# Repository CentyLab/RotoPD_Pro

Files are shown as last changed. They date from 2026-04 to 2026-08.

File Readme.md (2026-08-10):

## RotoPD Pro - USB-C PD 3.1 Breakout I2C 240W
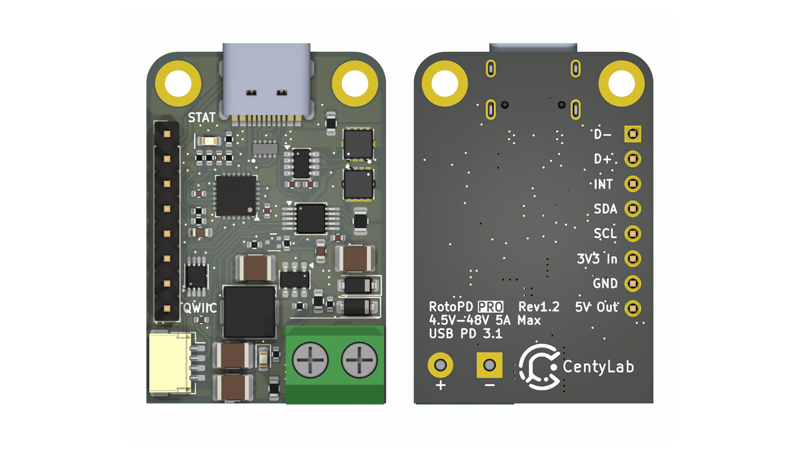
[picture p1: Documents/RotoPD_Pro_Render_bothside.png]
Render


## Related Links
- [AP33772S Arduino - GitHub](https://github.com/CentyLab/AP33772S-CentyLab)
- [INA238 Arduino - GitHub](https://github.com/RobTillaart/INA238)
- [RotoPD Pro Project - Hackaday](https://hackaday.io/project/204943-rotopd-pro-usb-c-240w-breakout-i2c)

You can install the libraries directly on ArduinoIDE. Library version 1.1.0 and later will support RotoPD Pro

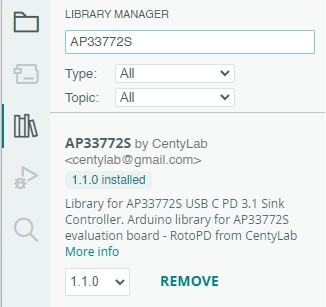
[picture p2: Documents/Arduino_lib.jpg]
AP33772SLib


## Description

While traditional power adapters can provide a variety of current but fixed to 5V output, our RotoPD Pro leverages advanced power delivery protocols to achieve a versatile output range — 4.5V to 48V at 240W max. The breakout board use a stand alone Power Delivery Sink controller to negotiate with your modern charger and provide different output voltage.

Centylab's RotoPD Pro can unlock more advance mode in your USB-C power supplies like Programmable Power Supply (PPS) and Adjustable Voltage Supply (AVS), to provide even more granular voltage adjustment. The RotoPD Pro simplifies power negotiation with USB-C adapters, handling the complex process of establishing power delivery contracts. The controller does all the heavy lifting of power negotiation and provides an easy way to configure over I2C, free your micro-controller from the complicated USB-C PD protocol.

To config the board, you will need an I2C bus. The board integrates seamlessly into the Qwiic and STEMMA QT ecosystems, no soldering is required. Unlike the previous version, the board only work with **3.3V I2C logic voltage.**

To make it even easier to use, RotoPD Pro includes a built-in buck converter that efficiently steps down USB-C VBUS power to a stable 5V output, making it perfect for powering microcontrollers, sensors, and other low-voltage components in your project.

## Requirements for AVS
To ultilize AVS power profile, you will need a powerbank or charger that has AVS profile and a 240W USB-C cable. Here are some chargers that we found support AVS profile.

+ [Framework 180W](https://frame.work/products/16-power-adapter)

+ [Framework 240W](https://frame.work/products/power-adapter-240w)

+ [AMEGAT Powerbank 140W](https://www.amazon.com/AMEGAT-27600mAh-Portable-Recharge-Compatible/dp/B0CC2CGD3L)

+ [Baseus Powerbank 140W](https://www.amazon.com/Baseus-Portable-Charger-24000mAh-Charging/dp/B0CH8D2YHZ)

+ [UGREEEN Nexode 300W](https://www.amazon.com/UGREEN-Charger-Charging-Station-Compatible/dp/B0DBZY57ZF)

## Specification
+ Input and output voltage range of  48V at 5A max
+ On board buck for 5V output at 1A max, 0.4A continuous
+ Support Qwiic or STEMMA QT connector with 3.3V logic
+ Support PD3.1 EPR/AVS Up to 48V and SPR/PPS Up to 21V
+ Certified USB PD3.1 v1.6  TID: 10062
+ Integrated ESD and flyback diode protection
+ Integrated NTC temperature monitoring
+ On board VBUS switch (back-to-back NMOS)
+ Current sensing from 0 to 5 A at ±2% accuracy up to 60C

## Pinout
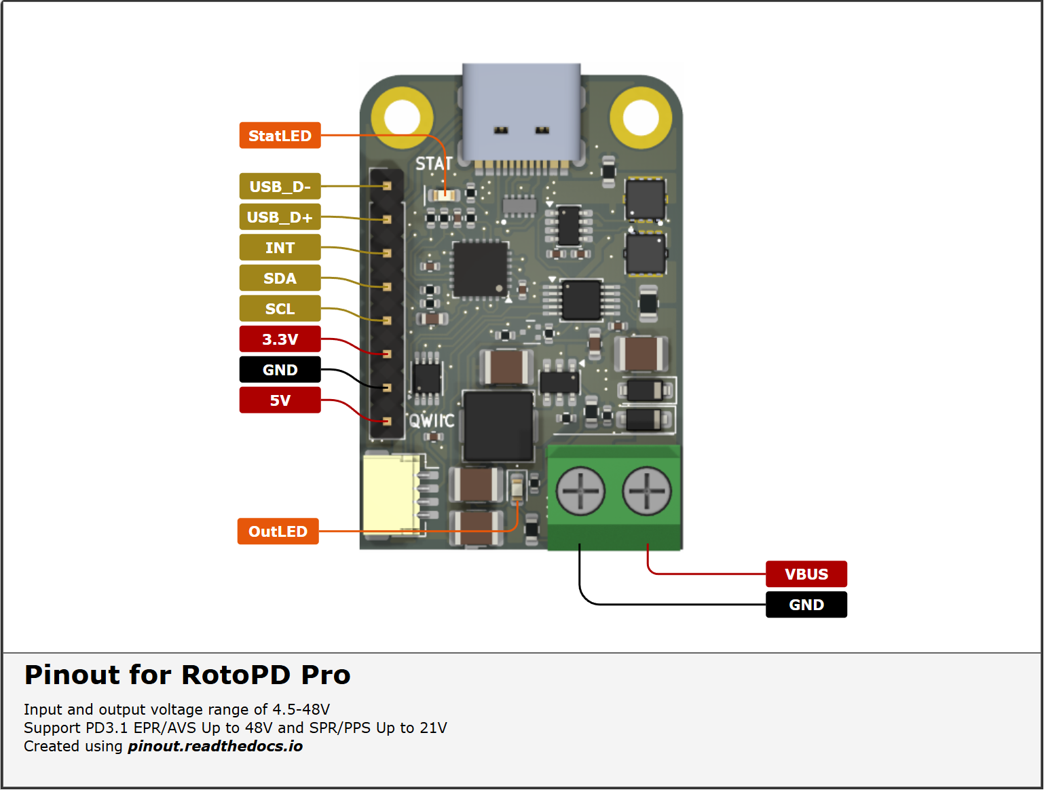
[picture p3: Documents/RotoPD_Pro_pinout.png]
Pinout

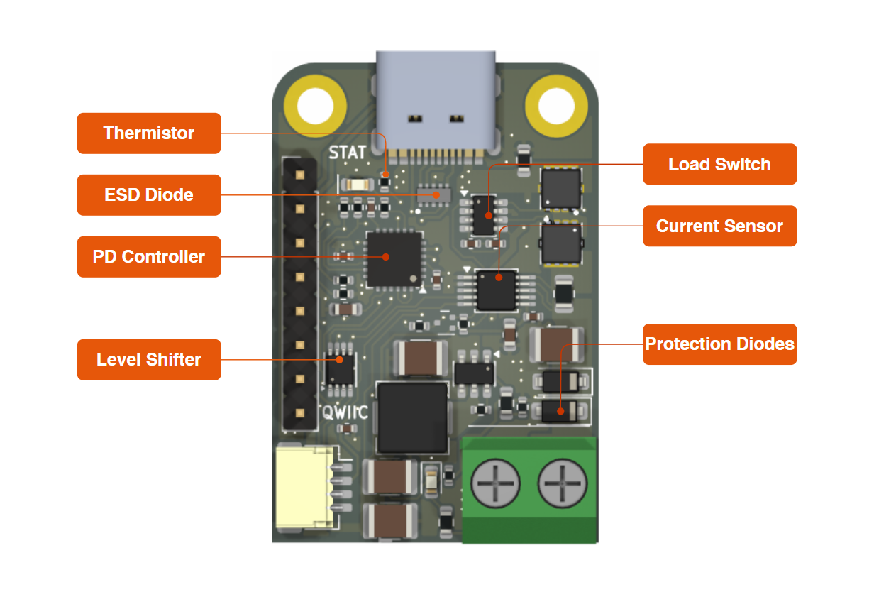
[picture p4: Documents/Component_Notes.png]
Components


## Schematic
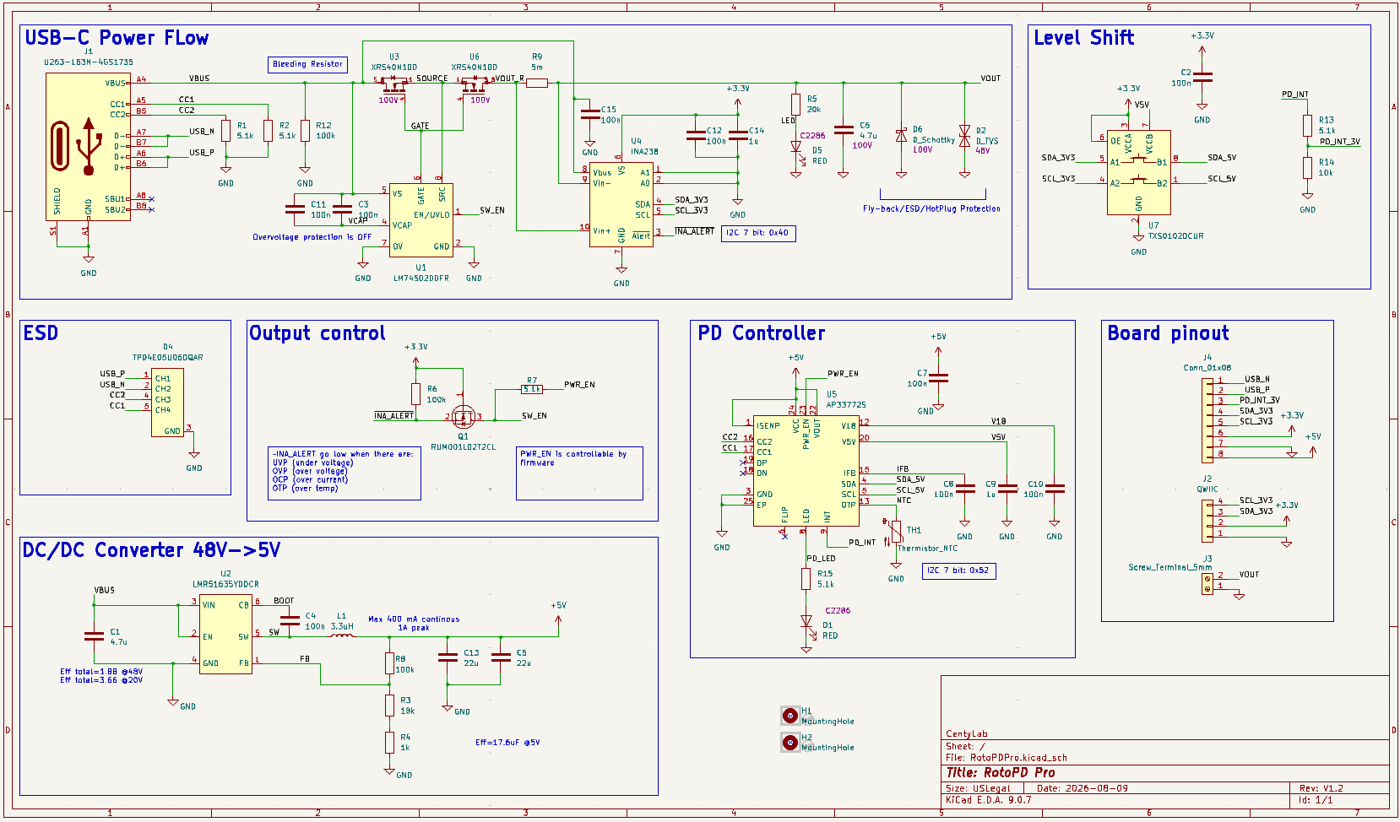
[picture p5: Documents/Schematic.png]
Schematic


## Demo
AVSCycle example with Sparkfun Pro Micro ESP32-C3. We are requesting AVS profile from 15V to 48V.

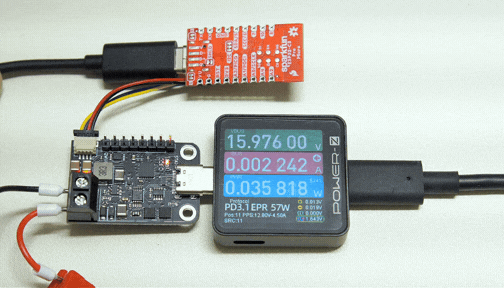
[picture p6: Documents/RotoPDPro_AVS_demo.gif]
ESP32C3_AVS_Step


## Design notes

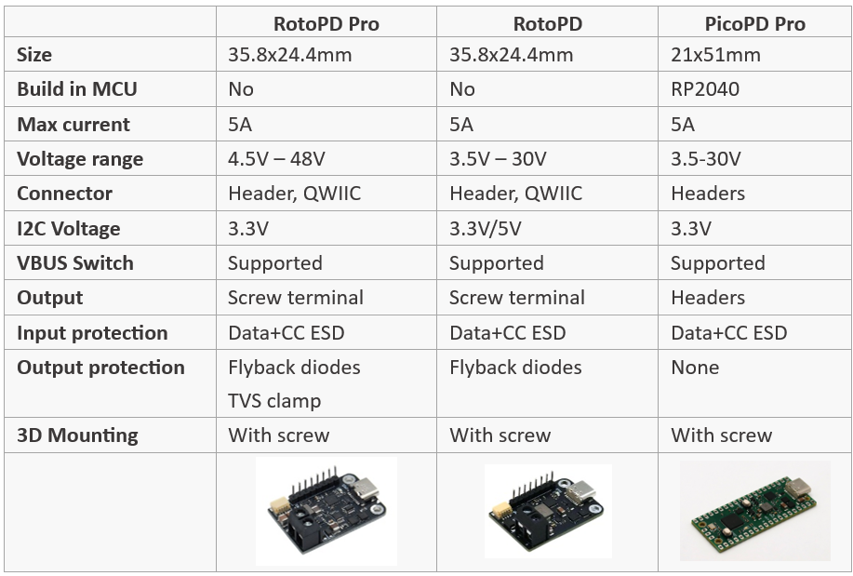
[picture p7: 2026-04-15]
Documents/Comparision_Table.png

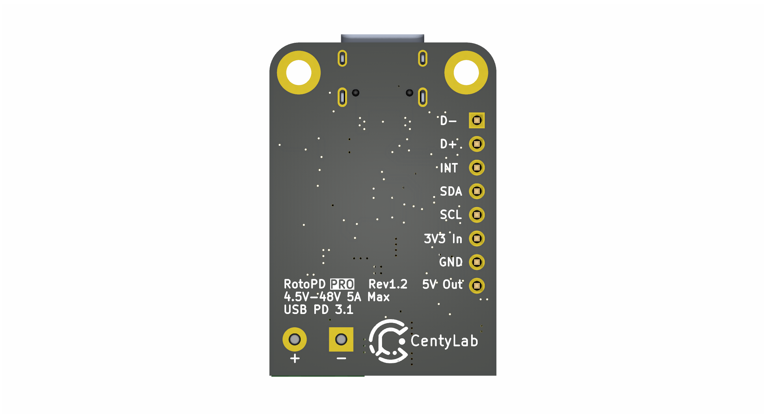
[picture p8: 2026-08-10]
Documents/Bottom_Render.png

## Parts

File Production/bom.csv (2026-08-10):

Designator | Footprint | Quantity | Value | LCSC Part #
C1, C6 | 1210 | 2 | 4.7u | C697607
C10, C11, C12, C15, C2, C3, C4, C7, C8 | 402 | 9 | 100n | C162179
C13, C5 | 1210 | 2 | 22u | C52306
C14, C9 | 603 | 2 | 1u | C15849
D1, D5 | 603 | 2 | RED | C2286
D2 | D_SOD-123F | 1 | D_TVS | C2994213
D4 | SON50P100X255X50-10N | 1 | TPD4E05U06DQAR | C138714
D6 | D_SOD-123 | 1 | D_Schottky | C908227
J1 | USB_C_XKB_240W | 1 | U263-163N-4GS1735 | C2931470
J2 | JST_SH_SM04B-SRSS-TB_1x04-1MP_P1.00mm_Horizontal | 1 | QWIIC | C160404
J3 | TerminalBlock_Phoenix_MKDS-1,5-2_1x02_P5.00mm_Horizontal | 1 | Screw_Terminal_5mm
J4 | PinHeader_1x08_P2.54mm_Vertical | 1 | Conn_01x08
L1 | L_APV_APH0530 | 1 | 3.3uH | C5349682
Q1 | SOT-723 | 1 | RUM001L02T2CL | C253528
R1, R13, R15, R2, R7 | 402 | 5 | 5.1k | C25905
R12 | 603 | 1 | 100k | C25803
R14 | 402 | 1 | 10k | C25744
R3 | 603 | 1 | 18k | C25810
R4 | 402 | 1 | 1k | C11702
R5 | 603 | 1 | 10k | C4184
R6, R8 | 402 | 2 | 100k | C25741
R9 | 805 | 1 | 5m | C22450690
TH1 | 402 | 1 | Thermistor_NTC | C77131
U1 | TSOT-23-8 | 1 | LM74502DDFR | C5219202
U2 | TSOT-23-6 | 1 | LMR51635YDDCR | C45262770
U3, U6 | DFN-8(3.3x3.3) | 2 | XRS40N10D | C50314150
U4 | VSSOP-10_3x3mm_P0.5mm | 1 | INA238 | C2868250
U5 | QFN-24-1EP_4x4mm_P0.5mm_EP2.6x2.6mm | 1 | AP33772S | C24374260
U7 | VSSOP-8_2.3x2mm_P0.5mm | 1 | TXS0102DCUR | C53434

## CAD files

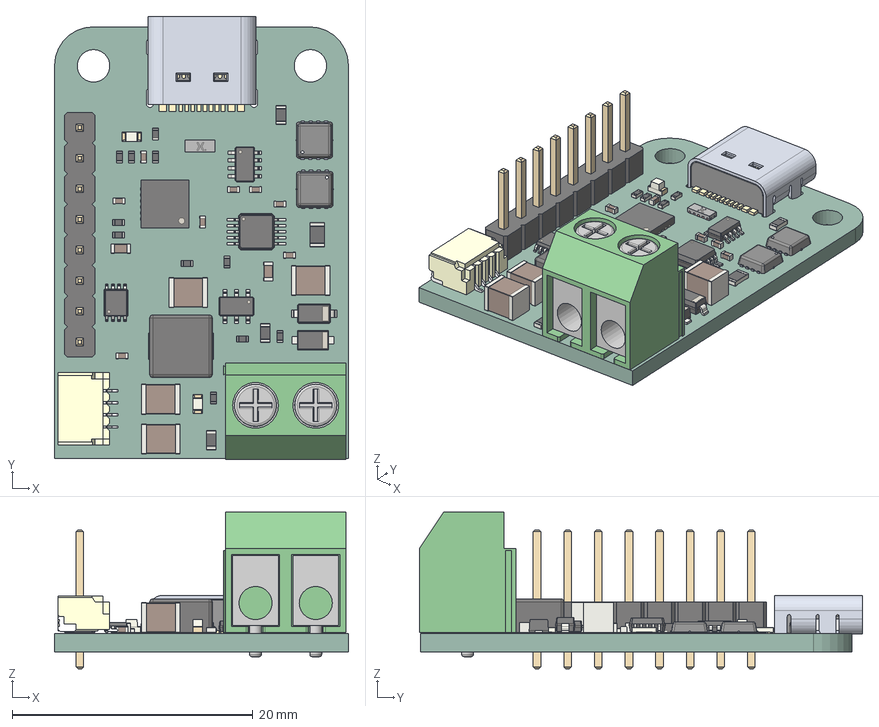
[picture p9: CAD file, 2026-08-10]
Documents/RotoPD_Pro.step
24.4 x 36.8 x 13.0 mm
LED_0603_1608Metric x 2
C_1210_3225Metric x 4
DFN-8(3.3x3.3) x 2
Screw Terminal Block 5mm 2-way
D_SOD-123
R_0603_1608Metric x 3
R_0402_1005Metric x 11
C_0402_1005Metric x 8
VSSOP-10_3x3mm_P0.5mm
TSOT-23-8
SOT1176 LF
SOT1176 Mold body
D_SOD-123F
C_0603_1608Metric x 2
L_APV_APH0530
SM04B-SRSS-TB(LF)(SN)
PinHeader_1x08_P2.54mm_Vertical
QFN-24-1EP_4x4mm_P0.5mm_EP2.6x2.6mm
VSSOP-8_2.3x2mm_P0.5mm
USBC_16P
R_0805_2012Metric
TSOT-23-6
RotoPDPro_PCB

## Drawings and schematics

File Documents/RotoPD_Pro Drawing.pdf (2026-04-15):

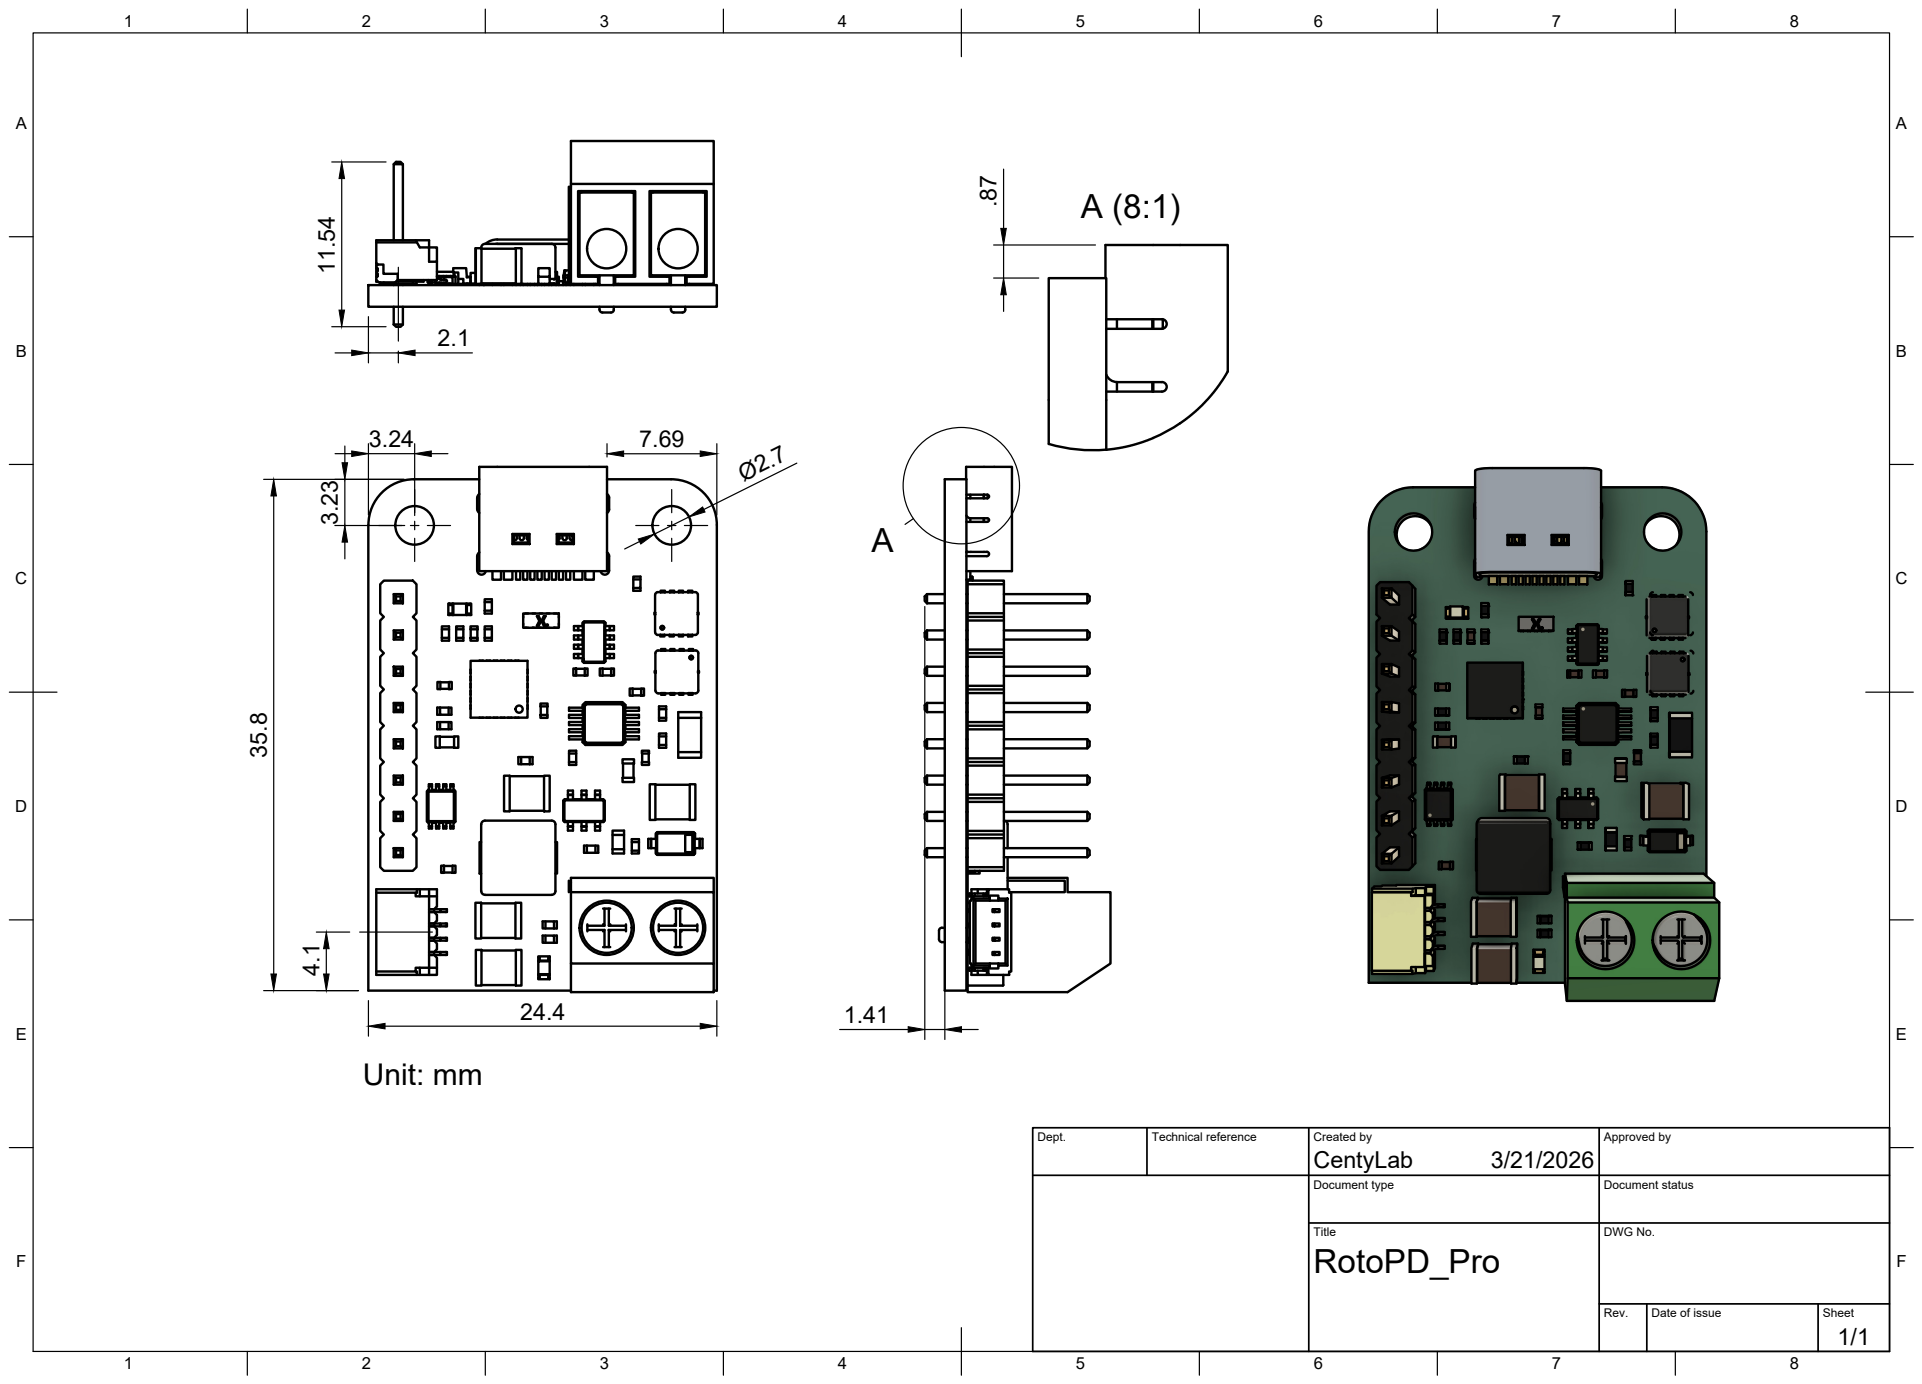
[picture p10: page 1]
Title; DWG No.; Rev.; Date of issue; Sheet; CentyLab 35.8; Unit: mm 3.23

Dept. | Technical reference | Created by 3/21/2026 | Approved by

Document type | Document status

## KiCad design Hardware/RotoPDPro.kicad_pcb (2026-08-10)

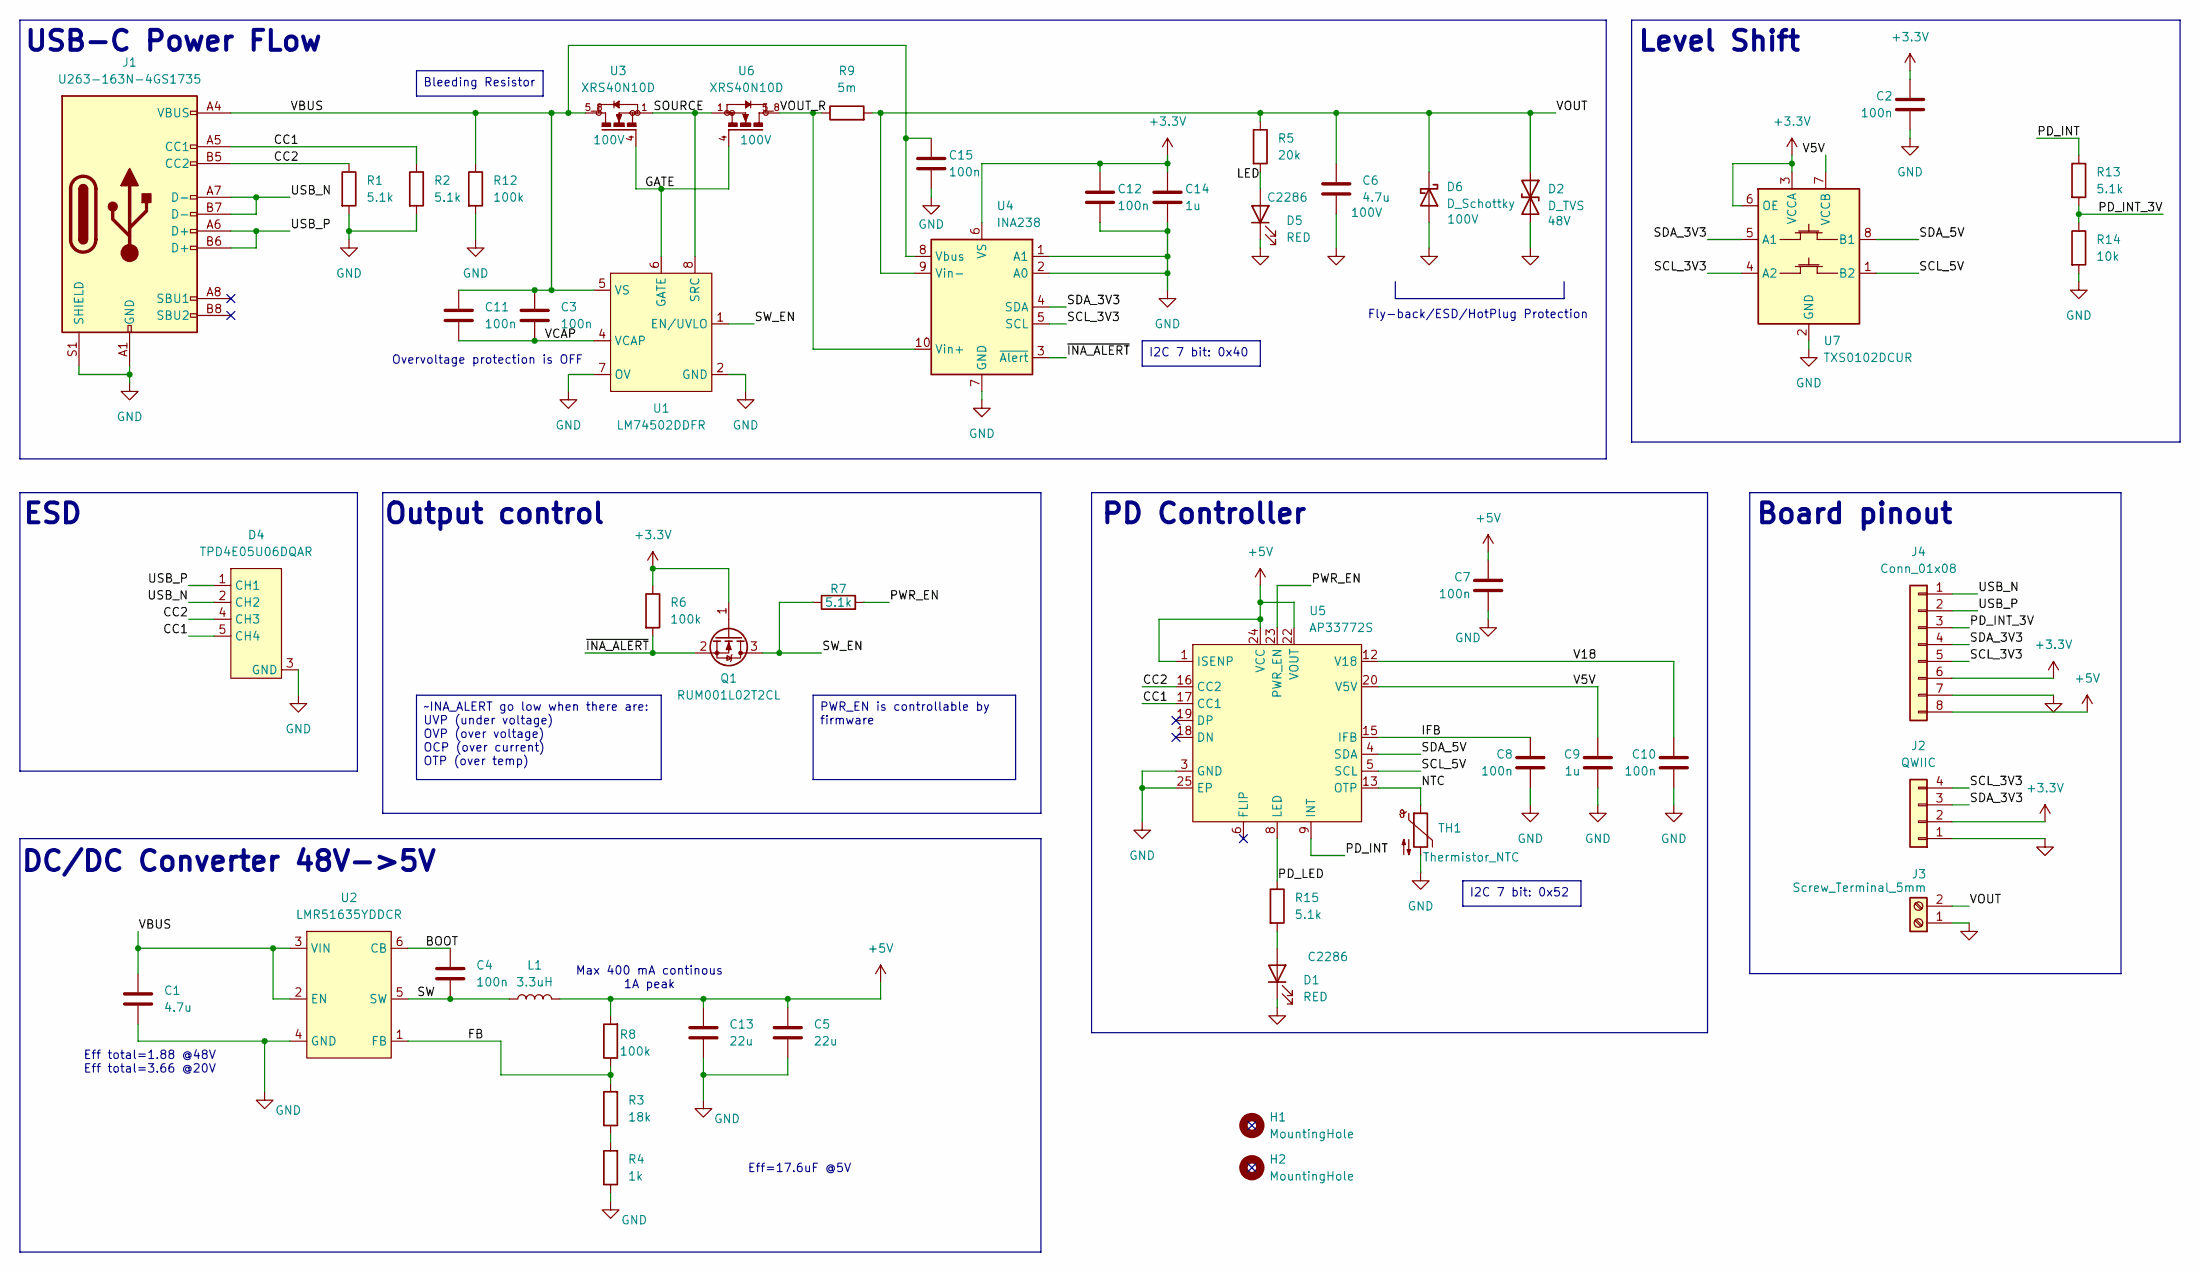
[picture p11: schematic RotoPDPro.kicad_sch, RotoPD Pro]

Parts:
C1: 4.7u; C_1210_3225Metric; LCSC C697607
C2, C3, C7, C8, C10, C11, C12, C15: 100n; C_0402_1005Metric; LCSC C162179
C4: 100n; R_0402_1005Metric; LCSC C162179
C5, C13: 22u; C_1210_3225Metric; LCSC C52306
C6: 4.7u; C_1210_3225Metric; Voltage 100V; LCSC C697607
C9, C14: 1u; C_0603_1608Metric; LCSC C15849
D1, D5: RED; LED_0603_1608Metric; LCSC C2286
D2: D_TVS; D_SOD-123F; Operating Voltage 48V; LCSC C2994213
D4: TPD4E05U06DQAR; SON50P100X255X50-10N; LCSC C138714
D6: D_Schottky; D_SOD-123; Voltage 100V; LCSC C908227
H1, H2: MountingHole; MountingHole_2.7mm_M2.5_DIN965_Pad_TopBottom
J1: U263-163N-4GS1735; USB_C_GSwitch; LCSC C2931470
J2: QWIIC; JST_SH_SM04B-SRSS-TB_1x04-1MP_P1.00mm_Horizontal; LCSC C160404
J3: Screw_Terminal_5mm; TerminalBlock_Phoenix_MKDS-1,5-2_1x02_P5.00mm_Horizontal
J4: Conn_01x08; PinHeader_1x08_P2.54mm_Vertical
L1: 3.3uH; L_APV_APH0530; LCSC C5349682
Q1: RUM001L02T2CL; SOT-723; LCSC C253528
R1, R2, R7, R13, R15: 5.1k; R_0402_1005Metric; LCSC C25905
R3: 18k; R_0603_1608Metric; LCSC C25810
R4: 1k; R_0402_1005Metric; LCSC C11702
R5: 20k; R_0603_1608Metric; LCSC C4184
R6, R8: 100k; R_0402_1005Metric; LCSC C25741
R9: 5m; R_0805_2012Metric; LCSC C22450690
R12: 100k; R_0603_1608Metric; LCSC C25803
R14: 10k; R_0402_1005Metric; LCSC C25744
TH1: Thermistor_NTC; R_0402_1005Metric; LCSC C77131
U1: LM74502DDFR; TSOT-23-8; LCSC C5219202
U2: LMR51635YDDCR; TSOT-23-6; LCSC Part C45262770
U3, U6: XRS40N10D; DFN-8(3.3x3.3); Voltage 100V; LCSC C50314150
U4: INA238; VSSOP-10_3x3mm_P0.5mm; LCSC C2868250
U5: AP33772S; QFN-24-1EP_4x4mm_P0.5mm_EP2.6x2.6mm; LCSC C24374260
U7: TXS0102DCUR; VSSOP-8_2.3x2mm_P0.5mm; LCSC C53434

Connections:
+3.3V: C2.1, C12.1, C14.1, J2.2, J4.6, Q1.1 (G), R6.1, U4.6 (VS), U7.3 (VCCA), U7.6 (OE)
+5V: C5.1, C7.1, C13.1, J4.8, L1.2, R8.2, U5.1 (ISENP), U5.22 (VOUT), U5.24 (VCC)
/BOOT: C4.2, U2.6 (CB)
/CC1: D4.5 (CH4), D4.6, J1.A5 (CC1), R2.1, U5.17 (CC1)
/CC2: D4.4 (CH3), D4.7, J1.B5 (CC2), R1.1, U5.16 (CC2)
/FB: R3.2, R8.1, U2.1 (FB)
/GATE: U1.6 (GATE), U3.4, U6.4
/IFB: C8.1, U5.15 (IFB)
/LED: D5.2 (A), R5.2
/NTC: TH1.1, U5.13 (OTP)
/PD_INT: R13.1, U5.9 (INT)
/PD_INT_3V: J4.3, R13.2, R14.1
/PD_LED: R15.1, U5.8 (LED)
/PWR_EN: R7.2, U5.23 (PWR_EN)
/SCL_3V3: J2.4, J4.5, U4.5 (SCL), U7.4 (A2)
/SCL_5V: U5.5 (SCL), U7.1 (B2)
/SDA_3V3: J2.3, J4.4, U4.4 (SDA), U7.5 (A1)
/SDA_5V: U5.4 (SDA), U7.8 (B1)
/SOURCE: U1.8 (SRC), U3.1, U3.2, U3.3, U6.1, U6.2, U6.3
/SW: C4.1, L1.1, U2.5 (SW)
/SW_EN: Q1.3 (D), R7.1, U1.1 (EN/UVLO)
/USB_N: D4.2 (CH2), D4.9, J1.A7 (D-), J1.B7 (D-), J4.1
/USB_P: D4.1 (CH1), D4.10, J1.A6 (D+), J1.B6 (D+), J4.2
/V5V: C9.1, U5.20 (V5V), U7.7 (VCCB)
/V18: C10.1, U5.12 (V18)
/VBUS: C1.1, C3.2, C11.2, C15.1, J1.A4 (VBUS), J1.A9 (VBUS), J1.B4 (VBUS), J1.B9 (VBUS), R12.1, U1.5 (VS), U2.2 (EN), U2.3 (VIN), U3.5_8, U4.8 (Vbus)
/VCAP: C3.1, C11.1, U1.4 (VCAP)
/VOUT: C6.1, D2.1 (A1), D6.1 (K), J3.2, R5.1, R9.2, U4.9 (Vin-)
/VOUT_R: R9.1, U4.10 (Vin+), U6.5_8
/~INA_ALERT: Q1.2 (S), R6.2, U4.3 (~Alert)
GND: C1.2, C2.2, C5.2, C6.2, C7.2, C8.2, C9.2, C10.2, C12.2, C13.2, C14.2, C15.2, D1.1 (K), D2.2 (A2), D4.3 (GND), D4.8 (GND), D5.1 (K), D6.2 (A), J1.A1 (GND), J1.A12 (GND), J1.B1 (GND), J1.B12 (GND), J1.S1 (SHIELD), J2.1, J3.1, J4.7, R1.2, R2.2, R4.1, R12.2, R14.2, TH1.2, U1.2 (GND), U1.7 (OV), U2.4 (GND), U4.1 (A1), U4.2 (A0), U4.7 (GND), U5.3 (GND), U5.25 (EP), U7.2 (GND)
unnamed: D1.2 (A), R15.2
unnamed: R3.1, R4.2
unnamed: U5.2 (NC), U5.7 (NC), U5.10 (NC), U5.11 (NC), U5.14 (NC), U5.21 (NC)

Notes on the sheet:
Output control
Eff total=1.88 @48V Eff total=3.66 @20V
DC/DC Converter 48V->5V
ESD
Eff=17.6uF @5V
Max 400 mA continous 1A peak
Level Shift
Overvoltage protection is OFF
PD Controller
USB-C Power FLow
Fly-back/ESD/HotPlug Protection
Board pinout
~INA_ALERT go low when there are: UVP (under voltage) OVP (over voltage) OCP (over current) OTP (over temp)
I2C 7 bit: 0x40
Bleeding Resistor
I2C 7 bit: 0x52
PWR_EN is controllable by firmware

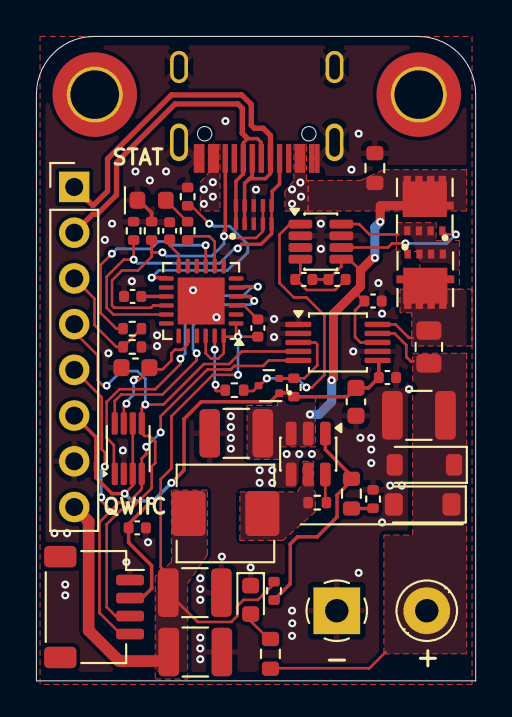
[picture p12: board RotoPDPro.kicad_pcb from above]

Board: 2 copper layers, 24.4 x 35.8 mm, 49 parts (0 on the bottom side), 34 nets.

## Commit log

2026-08-10 V1.2 Release
    [RotoPDPro.kicad_pcb, RotoPDPro.kicad_sch, RotoPD_Pro.step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]
2026-08-10 Update schematic
